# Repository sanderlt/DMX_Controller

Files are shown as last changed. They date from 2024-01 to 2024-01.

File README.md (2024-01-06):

# DMX512 LED Controller
Arduino DMX Controller. 48(16RGB) outputs. Based on 74HC595 Shift Registers.
Working voltage from 5 to 24v.

Files created in KiCad 7.0.1 and Arduino IDE 2.2.1

Firmware contain 20 programs. To switch betwin program please choose DMX address and fader to use specific program(see dmx_ctrl_nano_v.1.ino line 124 for options).

Planning to add smd AVR(or ARM) version

Demo video:

DEMO (https://www.youtube.com/shorts/KbOfjwnRDQc)

KiCad 3d wiew:

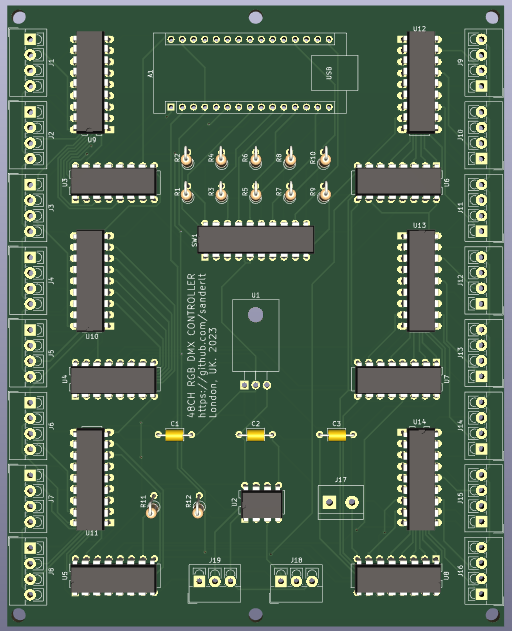
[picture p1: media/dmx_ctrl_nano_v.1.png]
KiCad 3d View:
 

KiCad PCB editor view:

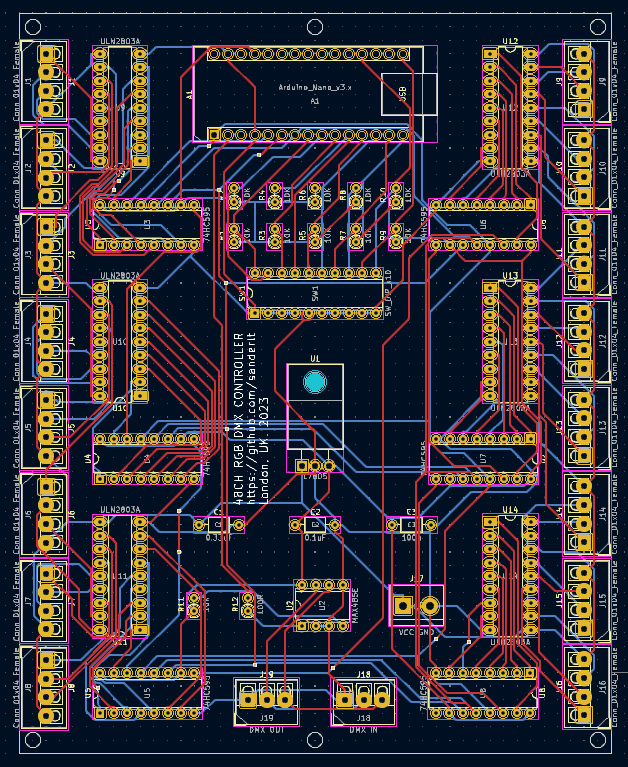
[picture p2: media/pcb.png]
KiCad PCB editor view:
 

Assembly Process(you can see earliest pcb version):

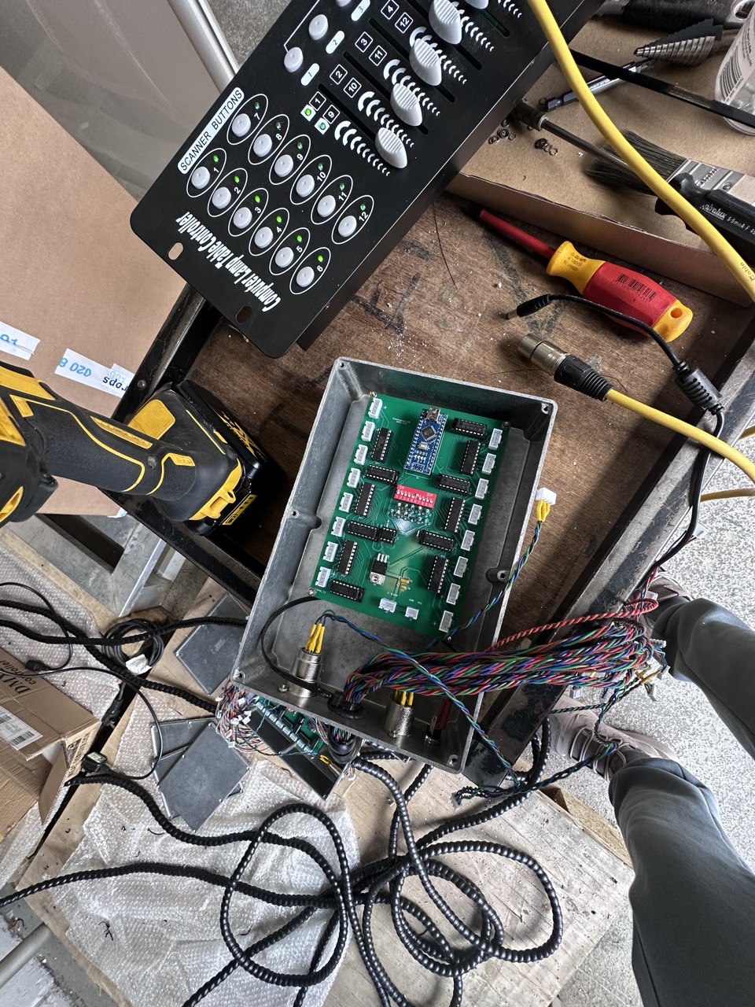
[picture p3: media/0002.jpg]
Assembly Process:
 

Final View:

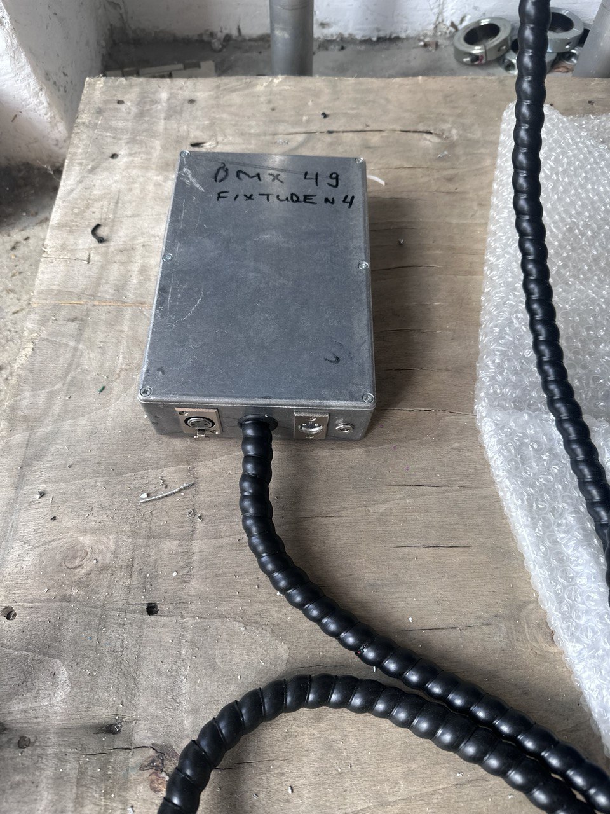
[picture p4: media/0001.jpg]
Final View:


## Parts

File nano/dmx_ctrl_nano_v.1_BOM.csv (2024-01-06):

Id | Designator | Footprint | Quantity | Designation | Supplier and ref
1 | J13,J15,J14,J11,J9,J1,J8,J10,J5,J3,J2,J4,J16,J7,J12,J6 | TerminalBlock_4Ucon_1x04_P3.50mm_Vertical | 16 | Conn_01x04_Female
2 | U1 | TO-220F-3_Horizontal_TabDown | 1 | L7805
3 | U8,U5,U4,U7,U3,U6 | DIP-16_W7.62mm | 6 | 74HC595
4 | U2 | DIP-8_W7.62mm | 1 | MAX485E
5 | U11,U9,U14,U13,U10,U12 | DIP-18_W7.62mm_LongPads | 6 | ULN2803A
6 | R5,R9,R3,R2,R4,R6,R7,R8,R1,R10,R11 | R_Axial_DIN0207_L6.3mm_D2.5mm_P2.54mm_Vertical | 11 | 10K
7 | J19 | TerminalBlock_4Ucon_1x03_P3.50mm_Vertical | 1 | DMX OUT
8 | C2 | C_Axial_L3.8mm_D2.6mm_P7.50mm_Horizontal | 1 | 0.1uF
9 | R12 | R_Axial_DIN0207_L6.3mm_D2.5mm_P2.54mm_Vertical | 1 | 100R
10 | SW1 | DIP-20_W7.62mm | 1 | SW_DIP_x10
11 | C3 | C_Axial_L3.8mm_D2.6mm_P7.50mm_Horizontal | 1 | 100u
12 | J17 | TerminalBlock_bornier-2_P5.08mm | 1 | VCC GND
13 | J18 | TerminalBlock_4Ucon_1x03_P3.50mm_Vertical | 1 | DMX IN
14 | A1 | Arduino_Nano | 1 | Arduino_Nano_v3.x
15 | C1 | C_Axial_L3.8mm_D2.6mm_P7.50mm_Horizontal | 1 | 0.33uF

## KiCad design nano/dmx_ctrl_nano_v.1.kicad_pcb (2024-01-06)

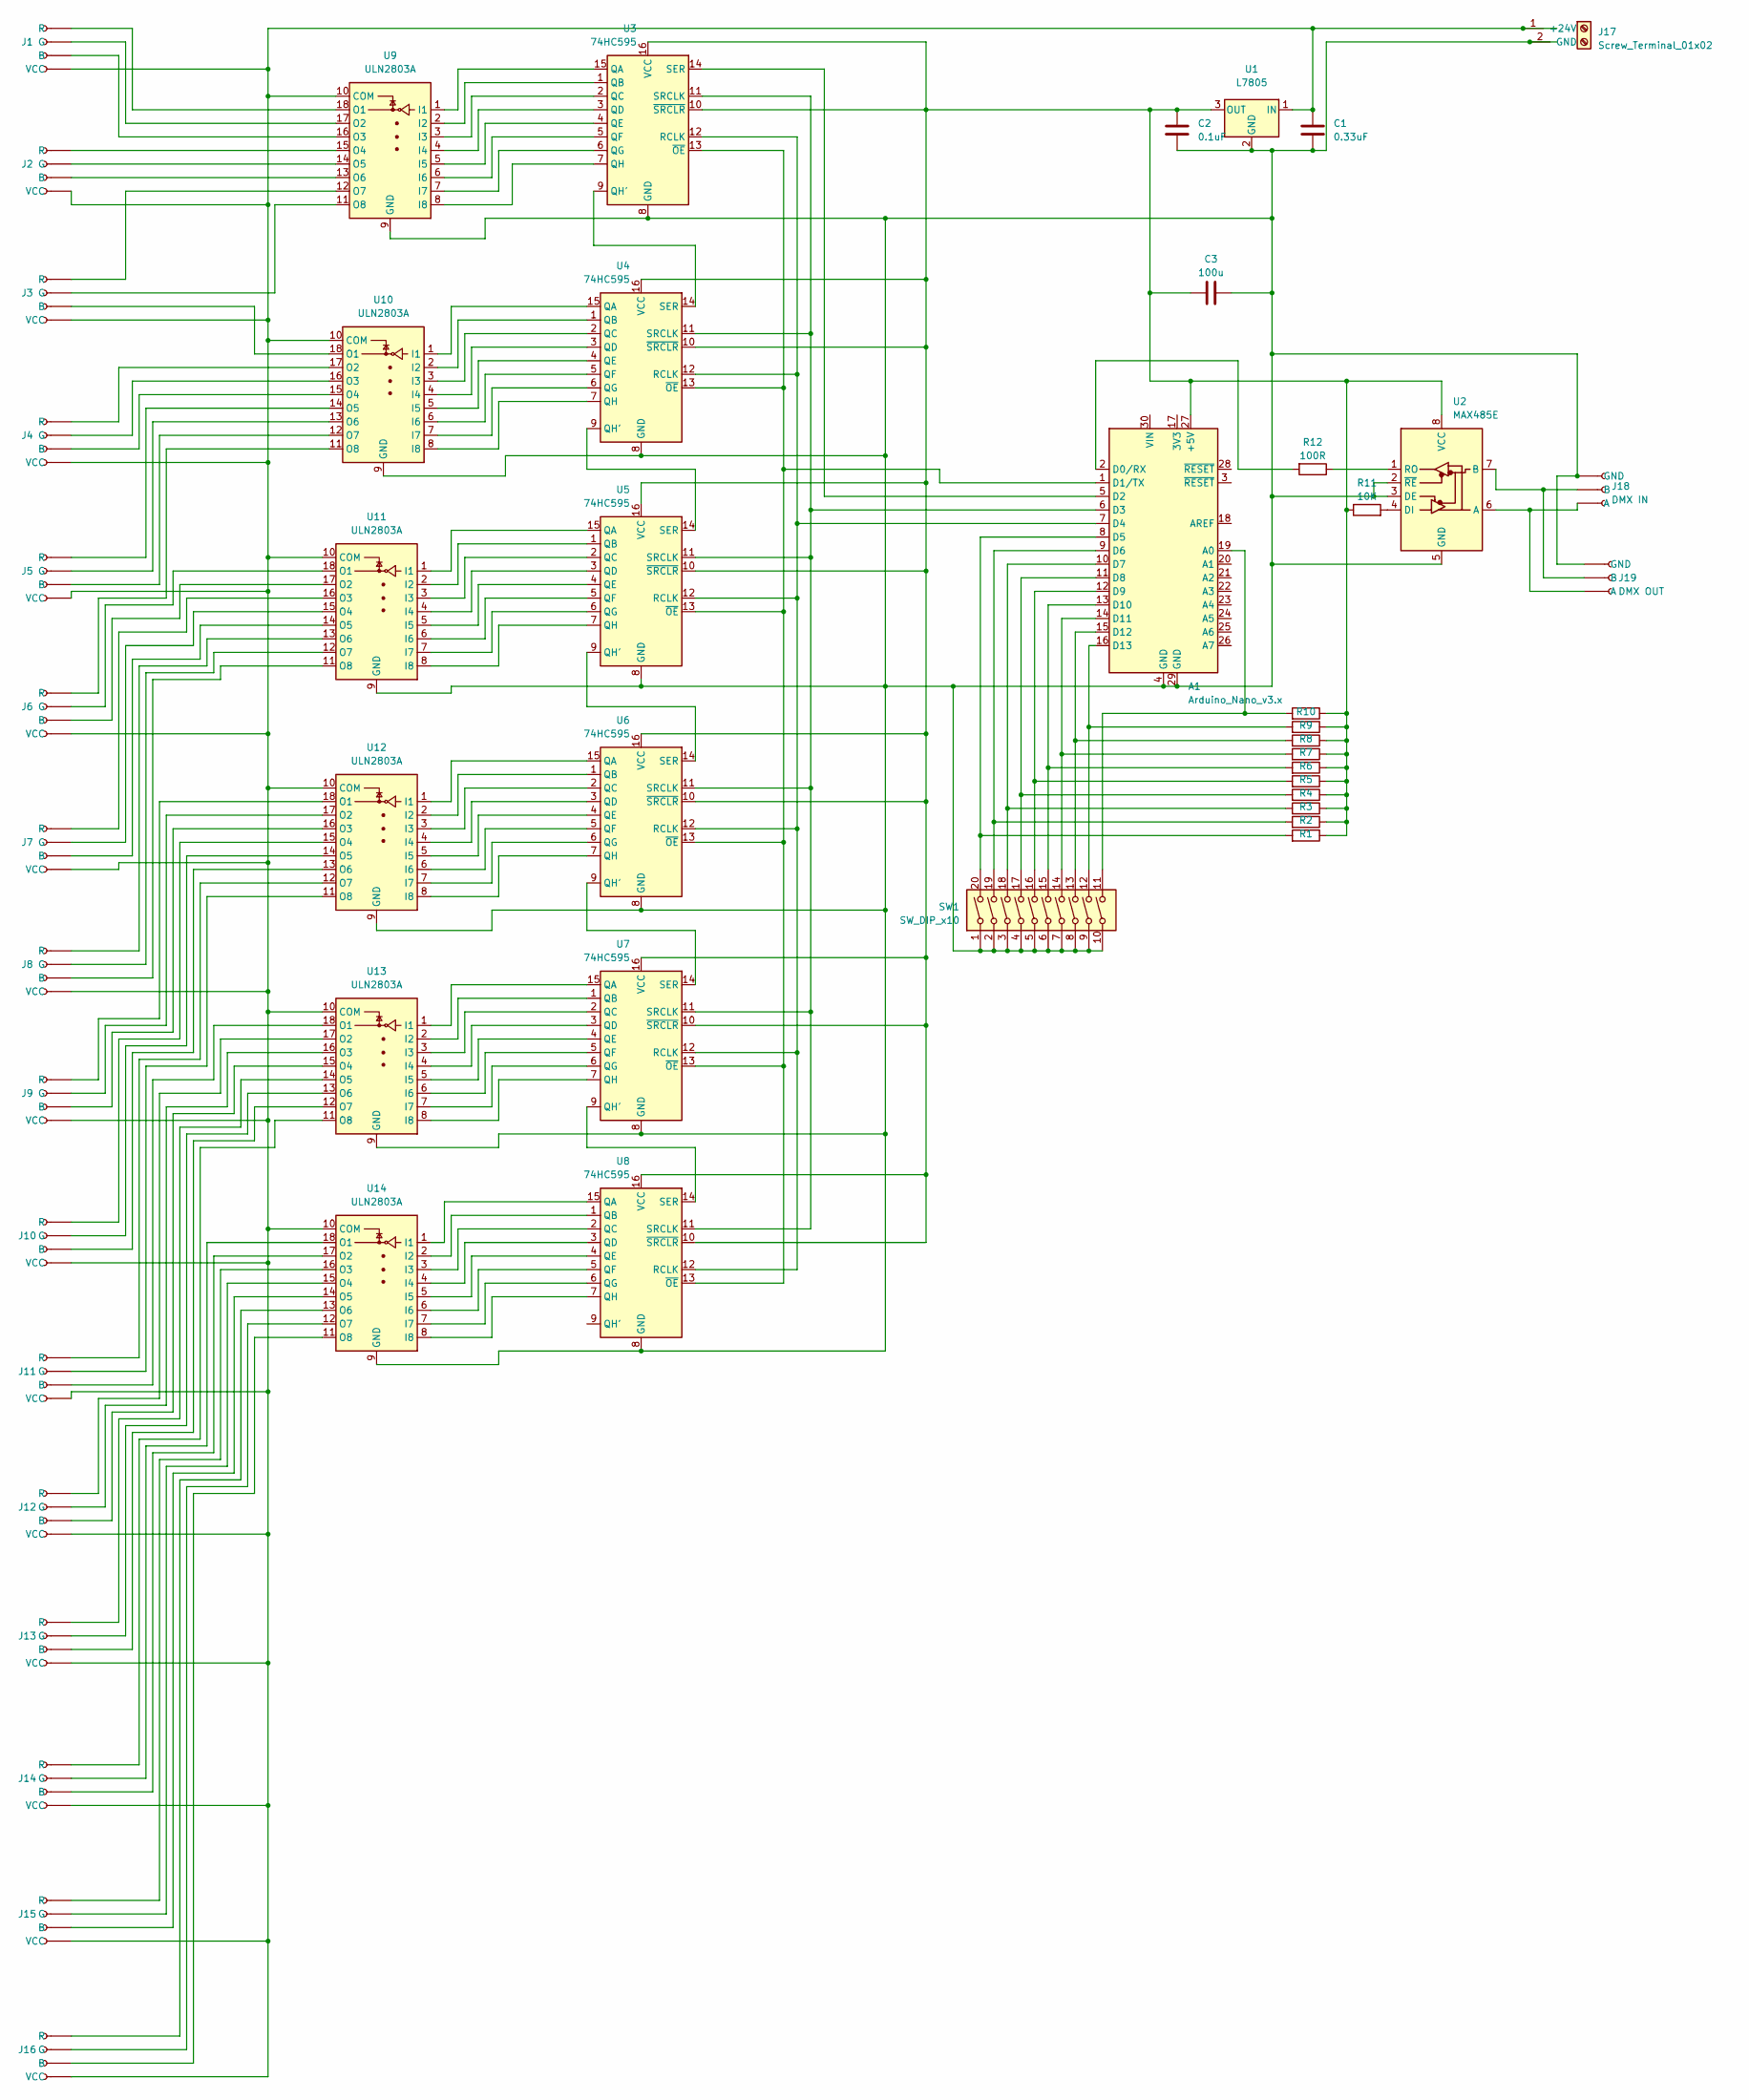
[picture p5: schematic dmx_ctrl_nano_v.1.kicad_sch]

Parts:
A1: Arduino_Nano_v3.x; Arduino_Nano
C1: 0.33uF; C_Axial_L3.8mm_D2.6mm_P7.50mm_Horizontal
C2: 0.1uF; C_Axial_L3.8mm_D2.6mm_P7.50mm_Horizontal
C3: 100u; C_Axial_L3.8mm_D2.6mm_P7.50mm_Horizontal
J1, J2, J3, J4, J5, J6, J7, J8, J9, J10, J11, J12, J13, J14, J15, J16: Conn_01x04_Female; TerminalBlock_4Ucon_1x04_P3.50mm_Vertical
J17: Screw_Terminal_01x02; TerminalBlock_bornier-2_P5.08mm
J18: DMX IN; TerminalBlock_4Ucon_1x03_P3.50mm_Vertical
J19: DMX OUT; TerminalBlock_4Ucon_1x03_P3.50mm_Vertical
R1, R2, R3, R4, R5, R6, R7, R8, R9, R10, R11: 10K; R_Axial_DIN0207_L6.3mm_D2.5mm_P2.54mm_Vertical
R12: 100R; R_Axial_DIN0207_L6.3mm_D2.5mm_P2.54mm_Vertical
SW1: SW_DIP_x10; DIP-20_W7.62mm
U1: L7805; TO-220F-3_Horizontal_TabDown
U2: MAX485E; DIP-8_W7.62mm
U3, U4, U5, U6, U7, U8: 74HC595; DIP-16_W7.62mm
U9, U10, U11, U12, U13, U14: ULN2803A; DIP-18_W7.62mm_LongPads

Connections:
unnamed: A1.27 (+5V), C2.1, C3.1, R1.1, R2.1, R3.1, R4.1, R5.1, R6.1, R7.1, R8.1, R9.1, R10.1, R11.1, U1.3 (OUT), U2.8 (VCC), U3.10 (~SRCLR), U3.16 (VCC), U4.10 (~SRCLR), U4.16 (VCC), U5.10 (~SRCLR), U5.16 (VCC), U6.10 (~SRCLR), U6.16 (VCC), U7.10 (~SRCLR), U7.16 (VCC), U8.10 (~SRCLR), U8.16 (VCC)
unnamed: A1.19 (A0), R10.2, SW1.11
unnamed: A1.2 (D0/RX), R12.2
unnamed: A1.1 (D1/TX), U3.13 (~OE), U4.13 (~OE), U5.13 (~OE), U6.13 (~OE), U7.13 (~OE), U8.13 (~OE)
unnamed: A1.5 (D2), U3.14 (SER)
unnamed: A1.6 (D3), U3.11 (SRCLK), U4.11 (SRCLK), U5.11 (SRCLK), U6.11 (SRCLK), U7.11 (SRCLK), U8.11 (SRCLK)
unnamed: A1.7 (D4), U3.12 (RCLK), U4.12 (RCLK), U5.12 (RCLK), U6.12 (RCLK), U7.12 (RCLK), U8.12 (RCLK)
unnamed: A1.8 (D5), R1.2, SW1.20
unnamed: A1.9 (D6), R2.2, SW1.19
unnamed: A1.10 (D7), R3.2, SW1.18
unnamed: A1.11 (D8), R4.2, SW1.17
unnamed: A1.12 (D9), R5.2, SW1.16
unnamed: A1.13 (D10), R6.2, SW1.15
unnamed: A1.14 (D11), R7.2, SW1.14
unnamed: A1.15 (D12), R8.2, SW1.13
unnamed: A1.16 (D13), R9.2, SW1.12
unnamed: J1.3 (B), U9.16 (O3)
unnamed: J1.2 (G), U9.17 (O2)
unnamed: J1.1 (R), U9.18 (O1)
unnamed: C1.1, J1.4 (VCC), J2.4 (VCC), J3.4 (VCC), J4.4 (VCC), J5.4 (VCC), J6.4 (VCC), J7.4 (VCC), J8.4 (VCC), J9.4 (VCC), J10.4 (VCC), J11.4 (VCC), J12.4 (VCC), J13.4 (VCC), J14.4 (VCC), J15.4 (VCC), J16.4 (VCC), J17.1 (+24V), U1.1 (IN), U9.10 (COM), U10.10 (COM), U11.10 (COM), U12.10 (COM), U13.10 (COM), U14.10 (COM)
unnamed: J2.3 (B), U9.13 (O6)
unnamed: J2.2 (G), U9.14 (O5)
unnamed: J2.1 (R), U9.15 (O4)
unnamed: J3.3 (B), U10.18 (O1)
unnamed: J3.2 (G), U9.11 (O8)
unnamed: J3.1 (R), U9.12 (O7)
unnamed: J4.3 (B), U10.15 (O4)
unnamed: J4.2 (G), U10.16 (O3)
unnamed: J4.1 (R), U10.17 (O2)
unnamed: J5.3 (B), U10.12 (O7)
unnamed: J5.2 (G), U10.13 (O6)
unnamed: J5.1 (R), U10.14 (O5)
unnamed: J6.3 (B), U11.17 (O2)
unnamed: J6.2 (G), U11.18 (O1)
unnamed: J6.1 (R), U10.11 (O8)
unnamed: J7.3 (B), U11.14 (O5)
unnamed: J7.2 (G), U11.15 (O4)
unnamed: J7.1 (R), U11.16 (O3)
unnamed: J8.3 (B), U11.11 (O8)
unnamed: J8.2 (G), U11.12 (O7)
unnamed: J8.1 (R), U11.13 (O6)
unnamed: J9.3 (B), U12.16 (O3)
unnamed: J9.2 (G), U12.17 (O2)
unnamed: J9.1 (R), U12.18 (O1)
unnamed: J10.3 (B), U12.13 (O6)
unnamed: J10.2 (G), U12.14 (O5)
unnamed: J10.1 (R), U12.15 (O4)
unnamed: J11.3 (B), U13.18 (O1)
unnamed: J11.2 (G), U12.11 (O8)
unnamed: J11.1 (R), U12.12 (O7)
unnamed: J12.3 (B), U13.15 (O4)
unnamed: J12.2 (G), U13.16 (O3)
unnamed: J12.1 (R), U13.17 (O2)
unnamed: J13.3 (B), U13.12 (O7)
unnamed: J13.2 (G), U13.13 (O6)
unnamed: J13.1 (R), U13.14 (O5)
unnamed: J14.3 (B), U14.17 (O2)
unnamed: J14.2 (G), U14.18 (O1)
unnamed: J14.1 (R), U13.11 (O8)
unnamed: J15.3 (B), U14.14 (O5)
unnamed: J15.2 (G), U14.15 (O4)
unnamed: J15.1 (R), U14.16 (O3)
unnamed: J16.3 (B), U14.11 (O8)
unnamed: J16.2 (G), U14.12 (O7)
unnamed: J16.1 (R), U14.13 (O6)
unnamed: A1.4 (GND), A1.29 (GND), C1.2, C2.2, C3.2, J17.2 (GND), J18.1 (GND), J19.1 (GND), SW1.1, SW1.2, SW1.3, SW1.4, SW1.5, SW1.6, SW1.7, SW1.8, SW1.9, SW1.10, U1.2 (GND), U2.2 (~RE), U2.3 (DE), U2.5 (GND), U3.8 (GND), U4.8 (GND), U5.8 (GND), U6.8 (GND), U7.8 (GND), U8.8 (GND), U9.9 (GND), U10.9 (GND), U11.9 (GND), U12.9 (GND), U13.9 (GND), U14.9 (GND)
unnamed: J18.3 (A), J19.3 (A), U2.6 (A)
unnamed: J18.2 (B), J19.2 (B), U2.7 (B)
unnamed: R11.2, U2.4 (DI)
unnamed: R12.1, U2.1 (RO)
unnamed: U3.15 (QA), U9.1 (I1)
unnamed: U3.1 (QB), U9.2 (I2)
unnamed: U3.2 (QC), U9.3 (I3)
unnamed: U3.3 (QD), U9.4 (I4)
unnamed: U3.4 (QE), U9.5 (I5)
unnamed: U3.5 (QF), U9.6 (I6)
unnamed: U3.6 (QG), U9.7 (I7)
unnamed: U3.9 (QH'), U4.14 (SER)
unnamed: U3.7 (QH), U9.8 (I8)
unnamed: U4.9 (QH'), U5.14 (SER)
unnamed: U5.9 (QH'), U6.14 (SER)
unnamed: U6.9 (QH'), U7.14 (SER)
unnamed: U7.9 (QH'), U8.14 (SER)
unnamed: U4.15 (QA), U10.1 (I1)
unnamed: U4.1 (QB), U10.2 (I2)
unnamed: U4.2 (QC), U10.3 (I3)
unnamed: U4.3 (QD), U10.4 (I4)
unnamed: U4.4 (QE), U10.5 (I5)
unnamed: U4.5 (QF), U10.6 (I6)
unnamed: U4.6 (QG), U10.7 (I7)
unnamed: U4.7 (QH), U10.8 (I8)
unnamed: U5.15 (QA), U11.1 (I1)
unnamed: U5.1 (QB), U11.2 (I2)
unnamed: U5.2 (QC), U11.3 (I3)
unnamed: U5.3 (QD), U11.4 (I4)
unnamed: U5.4 (QE), U11.5 (I5)
unnamed: U5.5 (QF), U11.6 (I6)
unnamed: U5.6 (QG), U11.7 (I7)
unnamed: U5.7 (QH), U11.8 (I8)
unnamed: U6.15 (QA), U12.1 (I1)
unnamed: U6.1 (QB), U12.2 (I2)
unnamed: U6.2 (QC), U12.3 (I3)
unnamed: U6.3 (QD), U12.4 (I4)
unnamed: U6.4 (QE), U12.5 (I5)
unnamed: U6.5 (QF), U12.6 (I6)
unnamed: U6.6 (QG), U12.7 (I7)
unnamed: U6.7 (QH), U12.8 (I8)
unnamed: U7.15 (QA), U13.1 (I1)
unnamed: U7.1 (QB), U13.2 (I2)
unnamed: U7.2 (QC), U13.3 (I3)
unnamed: U7.3 (QD), U13.4 (I4)
unnamed: U7.4 (QE), U13.5 (I5)
unnamed: U7.5 (QF), U13.6 (I6)
unnamed: U7.6 (QG), U13.7 (I7)
unnamed: U7.7 (QH), U13.8 (I8)
unnamed: U8.15 (QA), U14.1 (I1)
unnamed: U8.1 (QB), U14.2 (I2)
unnamed: U8.2 (QC), U14.3 (I3)
unnamed: U8.3 (QD), U14.4 (I4)
unnamed: U8.4 (QE), U14.5 (I5)
unnamed: U8.5 (QF), U14.6 (I6)
unnamed: U8.6 (QG), U14.7 (I7)
unnamed: U8.7 (QH), U14.8 (I8)

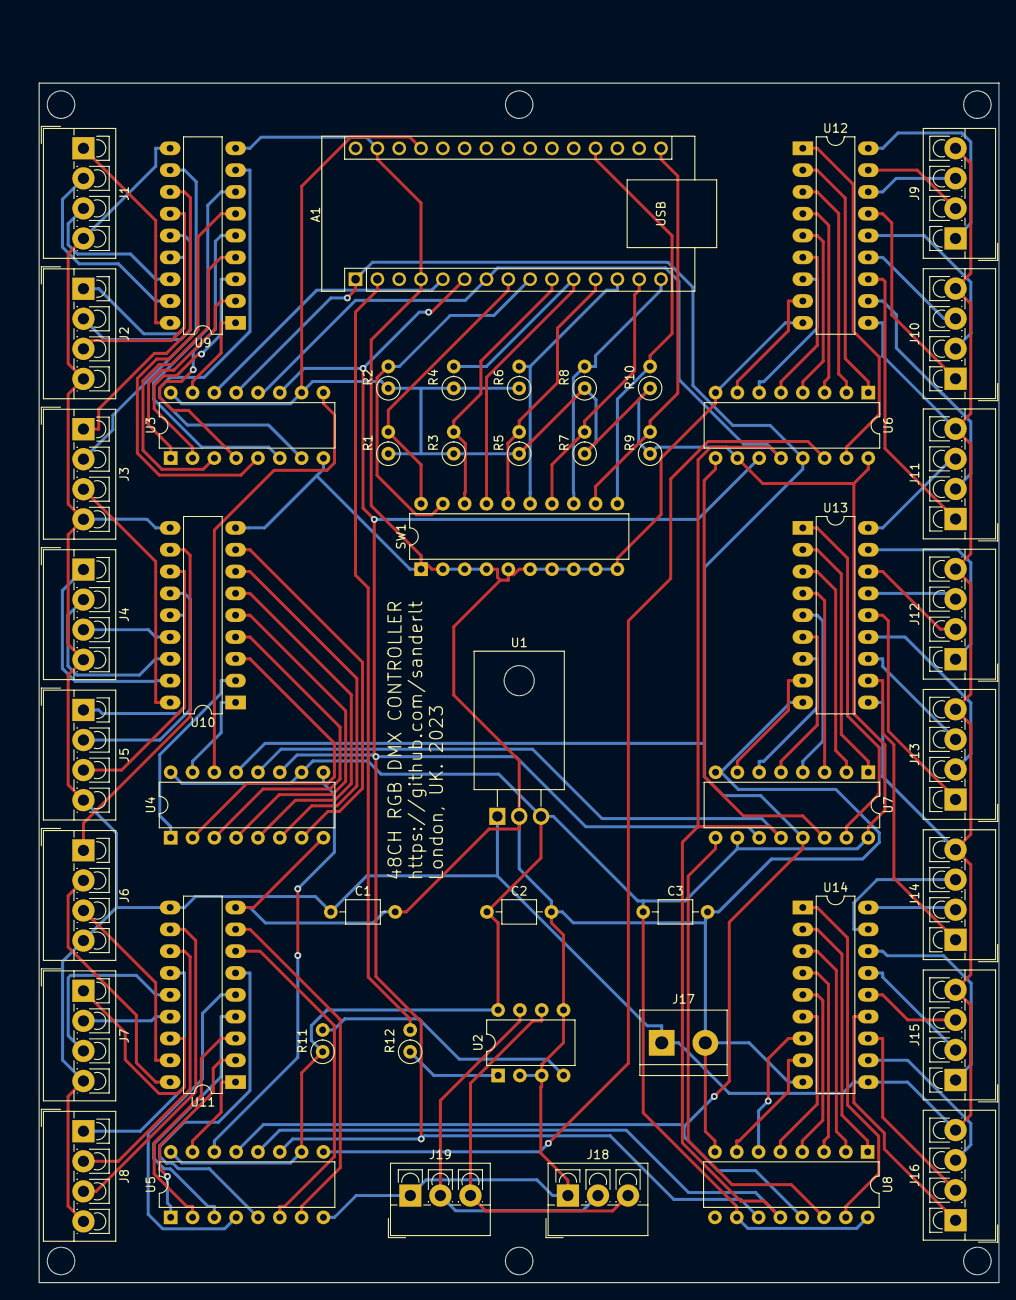
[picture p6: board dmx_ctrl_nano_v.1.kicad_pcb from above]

Board: 2 copper layers, 114.3 x 147.3 mm, 50 parts (0 on the bottom side), 123 nets.

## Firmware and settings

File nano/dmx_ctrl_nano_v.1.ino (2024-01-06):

// get the libary at:  https://github.com/mathertel/DMXSerial  by: mathertel
#include <DMXSerial.h>       
#define number_of_74hc595s 6
#define numOfRegisterPins number_of_74hc595s * 8
#define numRGBLeds 16

// DMX Settings
int startAddress = 0;  
int dmxUV = 0;
int dmxDelay = 100;

// Shift Register Pins
int enablePin = 1;
int dataPin = 2;
int clockPin = 3;
int latchPin = 4;

// DMX Address dip switches
int Input1 = 5;  
int Input2 = 6;  
int Input3 = 7;  
int Input4 = 8;  
int Input5 = 9;  
int Input6 = 10; 
int Input7 = 11;   
int Input8 = 12; 
int Input9 = 13; 
int Input10 = 14; // reserved for option

// Dip switch address state
int Dip1 = 0;
int Dip2 = 0;
int Dip3 = 0;
int Dip4 = 0;
int Dip5 = 0;
int Dip6 = 0;
int Dip7 = 0;
int Dip8 = 0;
int Dip9 = 0;
int Dip10 = 0;  // reserved for option

// alligning register to colour
int bluePin[]  = {0, 3, 6, 9, 12, 15, 18, 21, 24, 27, 30, 33, 36, 39, 42, 45};
int greenPin[] = {1, 4, 7, 10, 13, 16, 19, 22, 25, 28, 31, 34, 37, 40, 43, 46};
int redPin []  = {2, 5, 8, 11, 14, 17, 20, 23, 26, 29, 32, 35, 38, 41, 44, 47};

boolean registers[numOfRegisterPins];

void setup() {

  DMXSerial.init(DMXReceiver);
  
  pinMode(dataPin,  OUTPUT);
  pinMode(clockPin, OUTPUT);
  pinMode(latchPin, OUTPUT);
  digitalWrite(enablePin, LOW);

  pinMode(Input1, INPUT_PULLUP);
  pinMode(Input2, INPUT_PULLUP);
  pinMode(Input3, INPUT_PULLUP);
  pinMode(Input4, INPUT_PULLUP);
  pinMode(Input5, INPUT_PULLUP);
  pinMode(Input6, INPUT_PULLUP);
  pinMode(Input7, INPUT_PULLUP);
  pinMode(Input8, INPUT_PULLUP);
  pinMode(Input9, INPUT_PULLUP);
  pinMode(Input10, INPUT_PULLUP);

  // translate the dip switches inputs into a number
  if (digitalRead(Input1) == HIGH) {Dip1 = 0;}
  if (digitalRead(Input1) == LOW)  {Dip1 = 1;}

  if (digitalRead(Input2) == HIGH) {Dip2 = 0;}
  if (digitalRead(Input2) == LOW)  {Dip2 = 2;}

  if (digitalRead(Input3) == HIGH) {Dip3 = 0;}
  if (digitalRead(Input3) == LOW)  {Dip3 = 4;}

  if (digitalRead(Input4) == HIGH) {Dip4 = 0;}
  if (digitalRead(Input4) == LOW)  {Dip4 = 8;}

  if (digitalRead(Input5) == HIGH) {Dip5 = 0;}
  if (digitalRead(Input5) == LOW)  {Dip5 = 16;}

  if (digitalRead(Input6) == HIGH) {Dip6 = 0;}
  if (digitalRead(Input6) == LOW)  {Dip6 = 32;}

  if (digitalRead(Input7) == HIGH) {Dip7 = 0;}
  if (digitalRead(Input6) == LOW)  {Dip7 = 64;}

  if (digitalRead(Input8) == HIGH) {Dip8 = 0;}
  if (digitalRead(Input8) == LOW)  {Dip8 = 128;}

  if (digitalRead(Input9) == HIGH) {Dip9 = 0;}
  if (digitalRead(Input9) == LOW)  {Dip9 = 256;}

  if (digitalRead(Input10) == HIGH) {Dip10 = 1;}
  if (digitalRead(Input10) == LOW)  {Dip10 = 0;}  // reserved for option

// set the startAddress 
 startAddress = Dip1 + Dip2 + Dip3 + Dip4 + Dip5 + Dip6 + Dip7 + Dip8 + Dip9; 

  for (int i = numOfRegisterPins - 1; i >=  0; i--) {
    registers[i] = LOW;   
  }
  ledOff(0); 
}

void loop() {

// Calculate how long no data backet was received
  unsigned long lastPacket = DMXSerial.noDataSince();

   dmxUV =  DMXSerial.read(startAddress);          // first fixture channel <---- this is where you read the incomming DMX values 
   dmxDelay = DMXSerial.read(startAddress + 1);   // second fixture channel; for future use; maybe I implement a strobe function or add a extra colour 
   //if (dmxDelay > 45) dmxDelay = 45;
  
     if (lastPacket < 5000) {                  // it is less than 5 seconds after we received a DMX value 
    dmxUV = DMXSerial.read(startAddress);          
    digitalWrite(LED_BUILTIN, HIGH);       // display a normal operation and we receive a DMX value

     //  int dmxChanged = dmxUV;

switch (dmxUV) {
  case 1 ... 10:
        effect_1(1);//effect_X(how many time you want to repeat the effect.)
        ledOff(0);
    break;
  case 11 ... 20:
        effect_2(1);//effect_X(how many time you want to repeat the effect.)
        ledOff(0);
    break;
  case 21 ... 30:
        effect_3(1);//effect_X(how many time you want to repeat the effect.)
        ledOff(0);
    break;
  case 31 ... 40:
        effect_4(1);//effect_X(how many time you want to repeat the effect.)
        ledOff(0);
    break;
  case 41 ... 50:
        effect_5(1);//effect_X(how many time you want to repeat the effect.)
        ledOff(0);
    break;
  case 51 ... 60:
        effect_6(1);//effect_X(how many time you want to repeat the effect.)
        ledOff(0);
    break;
  case 61 ... 70:
        effect_7(1);//effect_X(how many time you want to repeat the effect.)
        ledOff(0);
    break;
  case 71 ... 80:
        effect_8(1);//effect_X(how many time you want to repeat the effect.)
        ledOff(0);
    break;
  case 81 ... 90:
        effect_9(1);//effect_X(how many time you want to repeat the effect.)
        ledOff(0);
    break;
   case 91 ... 100:
        effect_10(1);//effect_X(how many time you want to repeat the effect.)
        ledOff(0);
    break;
   case 101 ... 110:
        effect_11(1);//effect_X(how many time you want to repeat the effect.)
        ledOff(0);
    break;
    case 111 ... 120:
        effect_12(1);//effect_X(how many time you want to repeat the effect.)
        ledOff(0);
    break;
    case 121 ... 130:
        effect_13(1);//effect_X(how many time you want to repeat the effect.)
        ledOff(0);
    break;
    case 131 ... 140:
        effect_14(1);//effect_X(how many time you want to repeat the effect.)
        ledOff(0);
    break;
    case 141 ... 150:
        effect_15(1);//effect_X(how many time you want to repeat the effect.)
        ledOff(0);
    break;
    case 151 ... 160:
        effect_16(1);//effect_X(how many time you want to repeat the effect.)
        ledOff(0);
    break;
    case 161 ... 170:
        effect_17(1);//effect_X(how many time you want to repeat the effect.)
        ledOff(0);
    break;
    case 171 ... 180:
        effect_18(1);//effect_X(how many time you want to repeat the effect.)
        ledOff(0);
    break;
    case 181 ... 190:
        effect_19(1);//effect_X(how many time you want to repeat the effect.)
        ledOff(0);
    break;
    case 191 ... 200:
        effect_20(1);//effect_X(how many time you want to repeat the effect.)
        ledOff(0);
    break;
    case 201 ... 210:
        effect_1(1);//effect_X(how many time you want to repeat the effect.)
        ledOff(0);
    break;
    case 211 ... 255:
        effect_1(1);//effect_X(how many time you want to repeat the effect.)
        ledOff(0);
    break;
  default:
        //freq = 150.0;
        ////Serial.println(result);
        //Serial.println(result);
    // block of code default: do something when var is not equal to any of above label
    break;
}
 }
//   


else {
//  dmxDelay = 45; 
//  
//  effect_1(1);//effect_X(how many time you want to repeat the effect.)
//  ledOff(0);  //ledOff(leds off time )
//  effect_2(1);
//  ledOff(0);
//  effect_3(1);
//  ledOff(0);
//  effect_4(4);
//  ledOff(0);
//  effect_5(2);
//  ledOff(0);
//  effect_6(1);
//  ledOff(0);
//  effect_7(3);
//  ledOff(0);
//  effect_8(1);
//  ledOff(0);
//  effect_9(1);
//  ledOff(0);
//  effect_10(1);
//  ledOff(0);
//  effect_11(1);
//  ledOff(0);
//  effect_12(2);
//  ledOff(0);
//  effect_13(1);
//  ledOff(0);
//  effect_14(1);
//  ledOff(0);
//  effect_15(3);
//  ledOff(0);
//  effect_16(1);
//  ledOff(0);
//  effect_17(1);
//  ledOff(0);
//  effect_18(1);
//  ledOff(0);
//  effect_19(2);
//  ledOff(0);
//  effect_20(5);
//  ledOff(0);
//  delay(1000);
}
}
//////////////////////////////////////////////////////EFFECT 1
void effect_1(int repeatEffect) {
  for (int i = 1; i <= repeatEffect; i++) {
    Red(0, 14, 0);
    brigtness();
    //ledOff(0);

    Yellow(0, 14, 0);
    brigtness();
    //ledOff(0);

    Green(0, 14, 0);
    brigtness();
    //ledOff(0);

    White(0, 14, 0);
    brigtness();
    //ledOff(0);

    Cyan(0, 14, 0);
    brigtness();
    //ledOff(0);

    Blue(0, 14, 0);
    brigtness();
    //ledOff(0);

    Pink(0, 14, 0);
    brigtness();
    //ledOff(0);

    
  }
}
//////////////////////////////////////////////////////effect_2
void effect_2(int repeatEffect) {
  for (int i = 1; i <= repeatEffect; i++) {
    for (int i = 0; i <= 14; i++ ) {
      Red(0, i, 0);
      delay(dmxDelay);
      ledOff(0);

      Yellow(0, i, 0);
      delay(dmxDelay);
      ledOff(0);

      Green(0, i, 0);
      delay(dmxDelay);
      ledOff(0);

      White(0, i, 0);
      delay(dmxDelay);
      ledOff(0);

      Cyan(0, i, 0);
      delay(dmxDelay);
      ledOff(0);

      Blue(0, i, 0);
      delay(dmxDelay);
      ledOff(0);

      Pink(0, i, 0);
      delay(dmxDelay);
      ledOff(0);
    }
  }
}
//////////////////////////////////////////////////////effect_3
void effect_3(int repeatEffect) {
  for (int i = 1; i <= repeatEffect; i++) {
    for (int i = 0; i <= 14; i++) {
      registersWrite(redPin[i], HIGH);
      delay(dmxDelay);
    } ledOff(30);
    for (int i = 14; i >= 0; i--) {
      registersWrite(redPin[i], HIGH);
      registersWrite(bluePin[i], HIGH);
      delay(dmxDelay);
    } ledOffR(30);

    for (int i = 0; i <= 14; i++) {
      registersWrite(greenPin[i], HIGH);
      delay(dmxDelay);
    } ledOff(30);

    for (int i = 14; i >= 0; i--) {
      registersWrite(redPin[i], HIGH);
      registersWrite(greenPin[i], HIGH);
      delay(dmxDelay);
    } ledOffR(30);

    for (int i = 0; i <= 14; i++) {
      registersWrite(bluePin[i], HIGH);
      delay(dmxDelay);
    } ledOff(30);

    for (int i = 14; i >= 0; i--) {
      registersWrite(bluePin[i], HIGH);
      registersWrite(greenPin[i], HIGH);
      delay(dmxDelay);
    } ledOffR(30);

    for (int i = 0; i <= 14; i++) {
      registersWrite(bluePin[i], HIGH);
      registersWrite(redPin[i], HIGH);
      registersWrite(greenPin[i], HIGH);
      delay(dmxDelay);
    } ledOff(30);
  }
}
//////////////////////////////////////////////////////effect_4
void effect_4(int repeatEffect) {
  for (int i = 1; i <= repeatEffect; i++) {
    byte led = 0b10101010;
    byte led1 = 0b10101010;
    digitalWrite(latchPin, LOW);
    shiftOut(dataPin, clockPin, MSBFIRST, led);
    shiftOut(dataPin, clockPin, LSBFIRST, led1);
    digitalWrite(latchPin, HIGH);
    delay(dmxDelay);
    brigtnessNodelay();
    byte led2 = 0b01010101;
    byte led3 = 0b01010101;
    digitalWrite(latchPin, LOW);
    shiftOut(dataPin, clockPin, MSBFIRST, led2);
    shiftOut(dataPin, clockPin, LSBFIRST, led3);
    digitalWrite(latchPin, HIGH);
    delay(dmxDelay);
  }
}
//////////////////////////////////////////////////////effect_5
void effect_5(int repeatEffect) {
  for (int i = 1; i <= repeatEffect; i++) {
    Red(0, 1, 0);
    Yellow(2, 3, 0);
    Green(4, 5, 0);
    White(6, 7, 0);
    Cyan(8, 9, 0);
    Blue(10, 11, 0);
    Pink(12, 13, 0);
    Red(14, 14, 0);

    brigtness();
    for (int i = 1; i <= 5; i++) {
      turnOutputsOn();
      delay(dmxDelay);
      turnOutputsOff();
      delay(dmxDelay);
    }
  }
}
//////////////////////////////////////////////////////effect_6
void effect_6(int repeatEffect) {
  for (int i = 1; i <= repeatEffect; i++) {
    int count = 15;
    for (int i = 0; i < 15; i++) {
      ledOff(5);
      registersWrite(redPin[i], HIGH);  // chaser 1
      registersWrite(bluePin[count], HIGH); // chaser 2
      delay(dmxDelay);
      count--;
    }
    count = 15;
    for (int i = 0; i < 15; i++) {
      ledOff(5);
      registersWrite(redPin[i], HIGH);  // chaser 1
      registersWrite(greenPin[i], HIGH);
      registersWrite(bluePin[count], HIGH); // chaser 2
      delay(dmxDelay);
      count--;
    }
    count = 15;
    for (int i = 0; i < 15; i++) {
      ledOff(5);
      registersWrite(redPin[i], HIGH);  // chaser 1
      registersWrite(bluePin[i], HIGH);
      registersWrite(greenPin[count], HIGH); // chaser 2
      delay(dmxDelay);
      count--;
    }
  }
}
//////////////////////////////////////////////////////effect_7
void effect_7(int repeatEffect) {
  for (int i = 1; i <= repeatEffect; i++) {
    int count = 14;
    for (int i = 0; i <= 14; i++) {
      ledOff(0);
      registersWrite(redPin[i], HIGH);  // chaser 1
      registersWrite(redPin[i - 1], HIGH);
      brigtnessNodelay();
      registersWrite(bluePin[count], HIGH); // chaser 2
      registersWrite(bluePin[count - 1], HIGH); // chaser 2
      count--;
      delay(dmxDelay);
    }
  }
}
//////////////////////////////////////////////////////effect_8
void effect_8(int repeatEffect) {
  for (int i = 1; i <= repeatEffect; i++) {
    int count = 14;
    for (int i = 0; i <= 14; i++) {
      Cyan(0, i, 0);
      Cyan(0, i - count, 0);
      brigtnessNodelay();
      Pink(0, count, 0);
      Pink(0, count - i, 0);
      count--;
      delay(dmxDelay);
    }
    brigtnessNodelay();
    count = 14;
    for (int i = 0; i <= 14; i++) {
      Red(0, i, 0);
      Red(0, i - count, 0);
      brigtnessNodelay();
      Yellow(0, count, 0);
      Yellow(0, count - i, 0);
      count--;
      delay(dmxDelay);
    }
    brigtnessNodelay();
    count = 14;
    for (int i = 0; i <= 14; i++) {
      Blue(0, i, 0);
      Blue(0, i - count, 0);
      brigtnessNodelay();
      Green(0, count, 0);
      Green(0, count - i, 0);
      count--;
      delay(dmxDelay);
    }
  }
}
//////////////////////////////////////////////////////effect_9
void effect_9(int repeatEffect) {
  for (int i = 1; i <= repeatEffect; i++) {
    for (int i = 0; i < 15; i++) {
      for (int k = i; k < 15; k++) {
        registersWrite(greenPin[k], HIGH);
        delay(dmxDelay);
        registersWrite(greenPin[k], LOW);
        delay(30);
      }
      //registersWrite(redPin[i], HIGH);
      if (i < 2) {
        Red(0, i, 0);
      }
      if (i < 4) {
        Yellow(2, i, 0);
      }
      if (i < 6) {
        Green(4, i, 0);
      }
      if (i < 7) {
        White(6, i, 0);
      }
      if (i < 8) {
        Cyan(7, i, 0);
      }
      if (i < 10) {
        Blue(8, i, 0);
      }
      if (i < 15) {
        Pink(10, i, 0);
        delay(20);
      }
    }
  }
}
/////////////////////////////////////////////////////Effect_10
void effect_10(int repeatEffect) {
  for (int i = 1; i <= repeatEffect; i++) {
    for (int i = 14; i >= 0; i--) {
      for (int k = 0; k < i; k++) {
        registersWrite(redPin[k], HIGH);
        registersWrite(greenPin[k], HIGH);
        delay(dmxDelay);
        registersWrite(redPin[k], LOW);
        registersWrite(greenPin[k], LOW);
        delay(30);
      }

      registersWrite(bluePin[i], HIGH);
      delay(20);
    }
  }
}
/////////////////////////////////////////////////////Effect 11
void effect_11(int repeatEffect) {
  for (int i = 1; i <= repeatEffect; i++) {
    for (int i = 0; i <= 14; i++) {
      registersWrite(redPin[i], HIGH);
      delay(30);
      registersWrite(redPin[i - 4], LOW);
      delay(dmxDelay);
    } ledOff(0);
    for (int i = 14; i >= 0; i--) {
      registersWrite(bluePin[i], HIGH);
      delay(30);
      registersWrite(bluePin[i + 4], LOW);
      delay(dmxDelay);
    } ledOff(0);
    for (int i = 0; i <= 14; i++) {
      registersWrite(greenPin[i], HIGH);
      delay(30);
      registersWrite(greenPin[i - 4], LOW);
      delay(dmxDelay);
    } ledOff(0);
    for (int i = 14; i >= 0; i--) {
      registersWrite(bluePin[i], HIGH);
      registersWrite(greenPin[i], HIGH);
      registersWrite(redPin[i], HIGH);
      delay(30);
      registersWrite(bluePin[i + 4], LOW);
      registersWrite(greenPin[i + 4], LOW);
      registersWrite(redPin[i + 4], LOW);
      delay(dmxDelay);
    }
  }
}

/////////////////////////////////////////////////////effect_12
void effect_12(int repeatEffect) {
  for (int i = 1; i <= repeatEffect; i++) {
    int count = 14;
    for (int i = 0; i <= 14; i++) {
      registersWrite(bluePin[i], HIGH);  // chaser 1
      registersWrite(bluePin[i - 1], HIGH);
      registersWrite(bluePin[count], HIGH); // chaser 2
      registersWrite(bluePin[count - 1], HIGH); // chaser 2
      count--;
      delay(dmxDelay);
    }
    ledOff(0);
    count = 6;
    for (int i = 6; i >= 0; i--) {
      registersWrite(redPin[i], HIGH);  // chaser 1
      registersWrite(redPin[i - 1], HIGH);
      registersWrite(redPin[count], HIGH); // chaser 2
      registersWrite(redPin[count - 1], HIGH); // chaser 2
      count++;
      delay(dmxDelay);
    }
    ledOff(0);
    count = 14;
    for (int i = 0; i <= 14; i++) {
      registersWrite(greenPin[i], HIGH);  // chaser 1
      registersWrite(greenPin[i - 1], HIGH);
      registersWrite(greenPin[count], HIGH); // chaser 2
      registersWrite(greenPin[count - 1], HIGH); // chaser 2
      count--;
      delay(dmxDelay);
    }
    ledOff(0);
    count = 6;
    for (int i = 6; i >= 0; i--) {
      registersWrite(redPin[i], HIGH);
      registersWrite(bluePin[i], HIGH);
      registersWrite(greenPin[i], HIGH);
      brigtnessNodelay();
      registersWrite(redPin[i - 1], HIGH);
      registersWrite(bluePin[i - 1], HIGH);
      registersWrite(greenPin[i - 1], HIGH);
      brigtnessNodelay();
      registersWrite(redPin[count], HIGH);
      registersWrite(bluePin[count], HIGH);
      registersWrite(greenPin[count], HIGH);
      brigtnessNodelay();
      registersWrite(redPin[count - 1], HIGH);
      registersWrite(bluePin[count - 1], HIGH);
      registersWrite(greenPin[count - 1], HIGH);
      brigtnessNodelay();
      count++;
      delay(dmxDelay);
    }
    ledOff(0);
  }
}
/////////////////////////////////////////////////////effect_13
void effect_13(int repeatEffect) {
  for (int i = 1; i <= repeatEffect; i++) {
    for (int i = 0; i <= 14; i++) {
      for (int k = i; k <= 5; k++)
      {
        registersWrite(redPin[k], HIGH);
        registersWrite(bluePin[14 - k], HIGH);
        delay(dmxDelay);
        registersWrite(redPin[k], LOW);
        registersWrite(bluePin[14 - k], LOW);
        delay(dmxDelay);
      }
      registersWrite(greenPin[i], HIGH);
      registersWrite(bluePin[14 - i], HIGH);
      registersWrite(greenPin[14 - i], HIGH);
    }
  }
}

/////////////////////////////////////////////////////effect_14
void effect_14(int repeatEffect) {
  for (int i = 1; i <= repeatEffect; i++) {
    for (int i = 0; i <= 14; i++) {
      i = i + 1;
      if (i >= 1) {
        registersWrite(redPin[i], HIGH);
      }
      if (i >= 3) {
        registersWrite(redPin[i], HIGH);
        registersWrite(greenPin[i], HIGH);
        registersWrite(bluePin[i], LOW);
      }
      if (i >= 5) {
        registersWrite(greenPin[i], HIGH);
        registersWrite(bluePin[i], LOW);
        registersWrite(redPin[i], LOW);
      }
      if (i >= 7) {
        registersWrite(greenPin[i], HIGH);
        registersWrite(bluePin[i], HIGH);
        registersWrite(redPin[i], LOW);
      }
      if (i >= 9) {
        registersWrite(bluePin[i], HIGH);
        registersWrite(redPin[i], LOW);
        registersWrite(greenPin[i], LOW);
      }
      if (i >= 14) {
        registersWrite(bluePin[i], HIGH);
        registersWrite(redPin[i], HIGH);
        registersWrite(greenPin[i], LOW);
      }
      delay(dmxDelay);
    }
    ledOff(50);
    for (int i = 5; i >= 0; i--) {
      int  j = i * 2;
      if (j == 10) {
        registersWrite(redPin[j], HIGH);
      }
      if (j == 8) {
        registersWrite(redPin[j], HIGH);
        registersWrite(greenPin[j], HIGH);
        registersWrite(bluePin[j], LOW);
      }
      if (j == 6) {
        registersWrite(greenPin[j], HIGH);
        registersWrite(bluePin[j], LOW);
        registersWrite(redPin[j], LOW);
      }
      if (j == 4) {
        registersWrite(greenPin[j], HIGH);
        registersWrite(bluePin[j], HIGH);
        registersWrite(redPin[j], LOW);
      }
      if (j == 2) {
        registersWrite(bluePin[j], HIGH);
        registersWrite(redPin[j], LOW);
        registersWrite(greenPin[j], LOW);
      }
      if (j == 0) {
        registersWrite(bluePin[j], HIGH);
        registersWrite(redPin[j], HIGH);
        registersWrite(greenPin[j], LOW);
      }
      delay(dmxDelay);
    }
    ledOffR(50);
  }
}
/////////////////////////////////////////////////////effect_15
void effect_15(int repeatEffect) {
  for (int i = 1; i <= repeatEffect; i++) {
    for (int i = 14; i >= 0; i--) {
      if (i <= 14) {
        registersWrite(redPin[i], HIGH);
      }
      if (i <= 9) {
        registersWrite(redPin[i], HIGH);
        registersWrite(greenPin[i], HIGH);
        registersWrite(bluePin[i], LOW);
      }
      if (i <= 7) {
        registersWrite(greenPin[i], HIGH);
        registersWrite(bluePin[i], LOW);
        registersWrite(redPin[i], LOW);
      }
      if (i <= 5) {
        registersWrite(greenPin[i], HIGH);
        registersWrite(bluePin[i], HIGH);
        registersWrite(redPin[i], LOW);
      }
      if (i <= 3) {
        registersWrite(bluePin[i], HIGH);
        registersWrite(redPin[i], LOW);
        registersWrite(greenPin[i], LOW);
      }
      if (i <= 0) {
        registersWrite(bluePin[i], HIGH);
        registersWrite(redPin[i], HIGH);
        registersWrite(greenPin[i], LOW);
      }
      delay(dmxDelay);
    }
    ledOffR(10);
    for (int i = 0; i <= 14; i++) {
      if (i >= 0) {
        registersWrite(redPin[i], HIGH);
      }
      if (i >= 2) {
        registersWrite(redPin[i], HIGH);
        registersWrite(greenPin[i], HIGH);
        registersWrite(bluePin[i], LOW);
      }
      if (i >= 4) {
        registersWrite(greenPin[i], HIGH);
        registersWrite(bluePin[i], LOW);
        registersWrite(redPin[i], LOW);
      }
      if (i >= 6) {
        registersWrite(greenPin[i], HIGH);
        registersWrite(bluePin[i], HIGH);
        registersWrite(redPin[i], LOW);
      }
      if (i >= 8) {
        registersWrite(bluePin[i], HIGH);
        registersWrite(redPin[i], LOW);
        registersWrite(greenPin[i], LOW);
      }
      if (i >= 14) {
        registersWrite(bluePin[i], HIGH);
        registersWrite(redPin[i], HIGH);
        registersWrite(greenPin[i], LOW);
      }
      delay(dmxDelay);
    }
    ledOff(10);
  }
}
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

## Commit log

2024-01-06 Update and rename dmx_ctrl_nano_v.1.csv to nano/dmx_ctrl_nano_v.1.csv
    [dmx_ctrl_nano_v.1.csv]
2024-01-06 Update and rename dmx_ctrl_nano_v.1.kicad_pcb to nano/dmx_ctrl_nano_v.1.kicad_pcb
    [dmx_ctrl_nano_v.1.kicad_pcb]
2024-01-06 Update and rename dmx_ctrl_nano_v.1.kicad_sch to nano/dmx_ctrl_nano_v.1.kicad_sch
    [dmx_ctrl_nano_v.1.kicad_sch]
2024-01-06 Update and rename dmx_ctrl_nano_v.1.csv to dmx_ctrl_nano_v.1_BOM.csv
    [dmx_ctrl_nano_v.1_BOM.csv]
